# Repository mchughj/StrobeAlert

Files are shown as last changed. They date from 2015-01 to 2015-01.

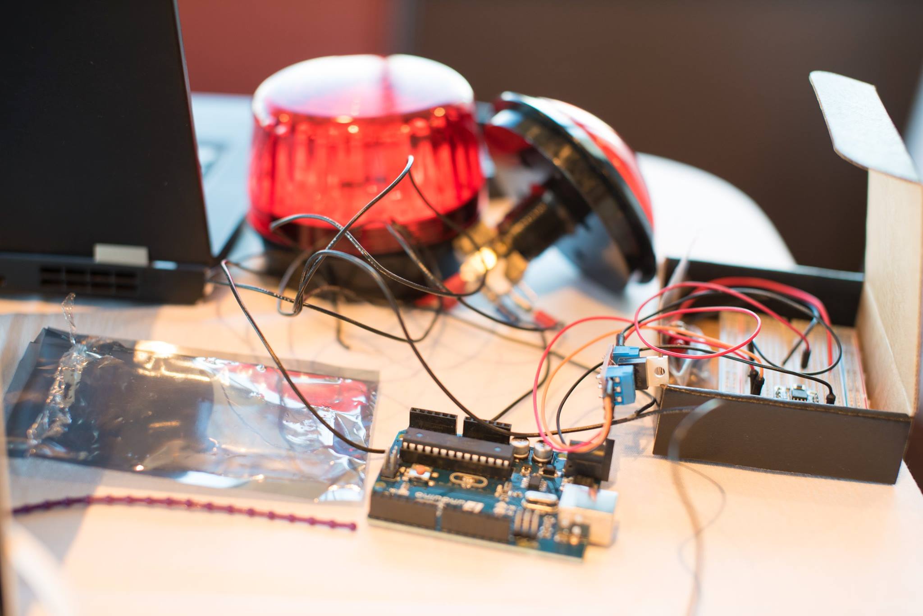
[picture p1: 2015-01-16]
Pictures/Electronics1.jpg

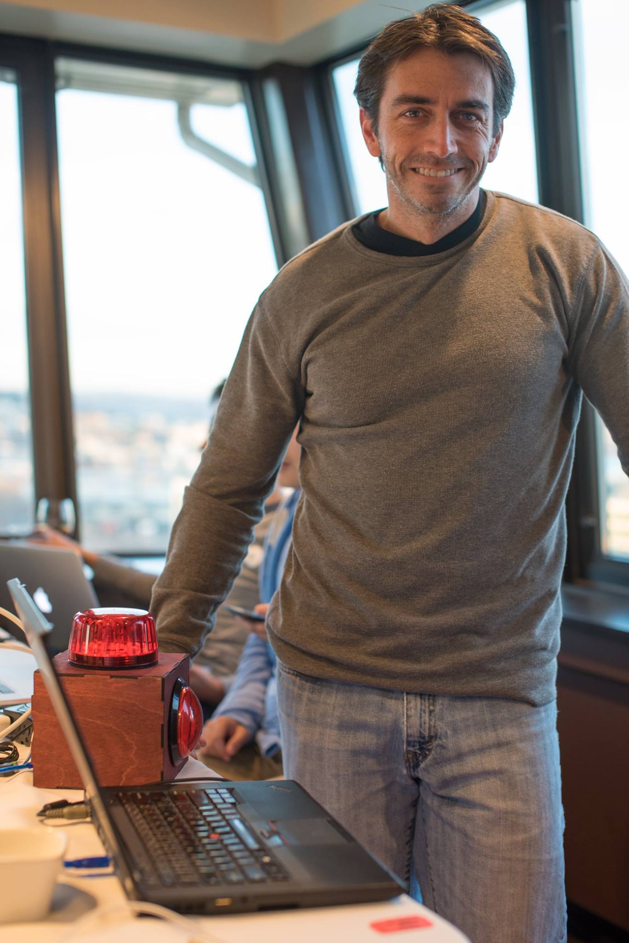
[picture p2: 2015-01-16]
Pictures/FinalBuild.jpg

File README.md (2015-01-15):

Strobe Alert
============

This was a hackday project in January 2015 at Facebook.  The intent was to create a device which would alert engineers when a server or service failure was ongoing.  Really the intent was to create an annoying box that we could put on our manager's desk so that he could share the pain of operational issues with the engineers.  

This repo contains the end result of that project.  We made a physical enclosure, drew a fritzing circuit diagram, wired up a mosfet, arduino, button, power, etc.  Wrote the arduino C code to receive serial commands, a python client application on the other end of the serial communication, and finally a server web process running on the correct side of a corporate firewall that could determine if there were engineering operational alerts present.

Bill of Materials
=================

- Arduino:          https://www.adafruit.com/products/50 - $25
- Big Dome button:  https://www.sparkfun.com/products/9181 - $10
- Mosfet breakout:  https://www.sparkfun.com/products/10256 - $4
- Strobe light:     http://www.amazon.com/Huoshang-Security-Alarm-Strobe-System/dp/B00IIFHAPC - $8
- USB Cable:        https://www.sparkfun.com/products/512 - $4
- Diode:            https://www.sparkfun.com/products/10926 - $0.15

Software Requirements
=====================
For the complete package you will need:
- Arduino development environment: http://arduino.cc/en/main/software
- Python 2.7
- PySerial: https://pypi.python.org/pypi/pyserial
- Fritzing: http://fritzing.org/home/

Enclosure
=========
Used the venerable http://www.makercase.com/.  
- Width: 180mm
- Height: 160
- Depth: 180
- Internal measures
- 2.6mm plywood
- Finger joint, 33mm distance
- Laser cutting Kerf - 0.0635mm - great setting for FS Laser Generation 5

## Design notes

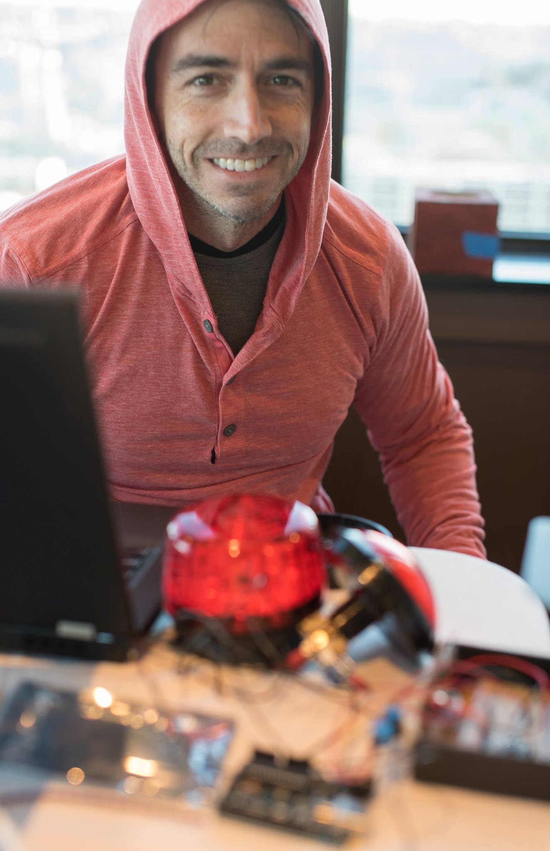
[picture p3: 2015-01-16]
Pictures/J2.jpg

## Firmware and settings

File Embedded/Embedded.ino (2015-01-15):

// vim: ts=4 sw=4 ft=cpp ai cindent

/**
 * Strobe Alert Embedded Software
 *
 * FB Hackathon
 * January 2015
 * Author: Jason McHugh  mchughj@fb.com
 *
 * If you have questions about this then feel free to ask.
 *
 * This is the application that runs on an Atmel processor, listens
 * for commands from the serial and uses a MOSFET (the RFP30N06LE)
 * to switch on and off a strobe light.
 */

#include <Serial>

#define CONTROL_PIN 2
#define BUTTON_PIN 4

#define BUTTON_TIME_DEBOUNCE 50
#define BUTTON_PRESS_ALARM_TIME 5000

int32_t durationRemaining;
unsigned long lastTimeSeen; 
unsigned long buttonPressTime;
int buttonState;

void setup() {
    Serial.begin(9600);
    delay(500);
    
    pinMode( CONTROL_PIN, OUTPUT );
    pinMode( BUTTON_PIN, INPUT_PULLUP );

    Serial.println( F("Done with setup") );
    durationRemaining = 0;
    buttonPressTime = 0;
    lastTimeSeen = millis();
}

void handleButtonPress() { 
  if( durationRemaining == -1 || durationRemaining > 0 ) { 
    durationRemaining = 0;
  } else {
    durationRemaining += BUTTON_PRESS_ALARM_TIME;
  }
}

void loop() {
    if( Serial.available() > 0 ) {
        consume_next_command();
    }
    
    unsigned long currentTime = millis();

    if( digitalRead( BUTTON_PIN ) == LOW ) {
      // The button is depressed.  Look to see if this is the first notification.
      if( buttonState != 1 ) { 
        // Ensure that a quick on-off-on doesn't trigger the same button action.
        if( currentTime - buttonPressTime > BUTTON_TIME_DEBOUNCE ) {
           Serial.print( F( "Button has been pressed; time: " ));
           Serial.println( currentTime );
           buttonState = 1;
           buttonPressTime = currentTime;
           handleButtonPress();
        }
      }
    } else if( buttonState == 1 ) { 
      Serial.println( F( "Button has been released;" ));
      buttonState = 0;
    }  
   
    unsigned long millisPassed = currentTime - lastTimeSeen;
    if( durationRemaining > 0 ) { 
      Serial.print( F( "Alarm is active; millisPassed: " ));
      Serial.print(millisPassed);
      Serial.print( F( ", durationRemaining: " ));
      Serial.println( durationRemaining );
      
      durationRemaining -= millisPassed;
      if( durationRemaining < 0 ) { 
        durationRemaining = 0;
       
        Serial.println( F( "Alarm duration has ended;" ));
      }
    }
    lastTimeSeen = currentTime;
    
    if( durationRemaining > 0 || durationRemaining == -1 ) {
      digitalWrite( CONTROL_PIN, 1 );
    } else {
      digitalWrite( CONTROL_PIN, 0 );
    }
    delay(10);
}

// Read the next command and handle consuming that specific command.
void consume_next_command() {
    Serial.println( F("Going to consume next command") );
    uint32_t command = Serial.parseInt();
    Serial.print( F("Command; command: ") );
    Serial.println( command );
    if( command == 1 ) {
        uint32_t duration = Serial.parseInt();
        Serial.print( F("Adding time to the durationRemaining; duration: ") );
        Serial.println( duration );
        
        if( duration == -1 ) { 
          durationRemaining = -1;
        } else {
          durationRemaining += duration;
        }
    } else if( command == 2 ) {
        durationRemaining = 0;
    } else {
        Serial.print( F("Unexpected command; command: ") );
        Serial.println( command );
    }
}

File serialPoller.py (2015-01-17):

import serial
import serial.tools.list_ports
import sys
import time
import httplib

# Super simple test harness to ensure that the embedded program running on the arduino 
# is functioning.

serverInstance = "pechuk.devserver"
serverPort = 8080
defaultAlarmDuration = 10000

def findSerialPort():
    for l in list(serial.tools.list_ports.comports()):
       if l[1].find( "rduino") != -1:
          return l[0]
    
    print "Unable to find arduino in: " + str(list(serial.tools.list_ports.comports()))

def main():
    serial_speed = 9600
    serial_port = findSerialPort()

    print "Establishing the communication with the arduino on " + serial_port

    ser = serial.Serial(serial_port, serial_speed, timeout=1)

    print "Waiting for arduino bootloader to finish"
    time.sleep(2)
    print "Connected"

    while( 1 ):
       try: 
           print "Connecting to " + serverInstance
           connection = httplib.HTTPConnection(serverInstance, serverPort, timeout=30)
           print "Making http request"
           connection.request( "GET", "/" )
           result = connection.getresponse()
       
           print result.status, result.reason

           if result.status == 200: 
               count = int(result.read())
               print "Number of alerts: " + str(count)
               if count > 0:
                   s = "1," + str(defaultAlarmDuration) + "\n";
                   ser.write(s);

       except Exception as e:  
           print "Exception: " + str(e)


       print "Reading from arduino: "
       bytesRead = 0
       while( bytesRead < 4096 ):
           b = ser.read()
           if( b == "" ):
               break
           else:
               print str(b),
           bytesRead = bytesRead + 1

       if bytesRead > 0:
           print

       print "Sleeping"
       time.sleep(10)    



if __name__ == "__main__":
    main()

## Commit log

2015-01-15 Updated with enclosure information
2015-01-16 Circuit change and some pictures
    [Circuit.fzz]
